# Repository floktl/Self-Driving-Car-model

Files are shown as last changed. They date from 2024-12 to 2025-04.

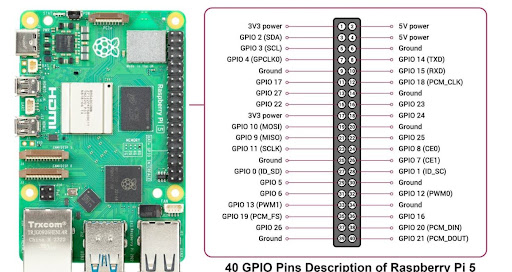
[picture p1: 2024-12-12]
Documentation/pinout_raspberry.jpg

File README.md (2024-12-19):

# Self-Driving Car Model 🚗🤖

Welcome to the **Self-Driving Car Model** project! This repository hosts the development of a small-scale self-driving car designed to provide hands-on experience in embedded systems and robotics applications. Whether you're a hobbyist, student, or professional looking to delve into autonomous vehicle technology, this project offers a comprehensive platform to learn, experiment, and innovate.

## Table of Contents
- [About the Project](#about-the-project)
- [Goals](#goals)
- [Learning Benefits](#learning-benefits)
- [Features](#features)
- [Technologies Used](#technologies-used)
- [Getting Started](#getting-started)
  - [Prerequisites](#prerequisites)
- [Usage](#usage)
- [Contributing](#contributing)
- [License](#license)
- [Contact](#contact)

## About the Project

The **Self-Driving Car Model** is an educational and experimental project aimed at developing a miniature autonomous vehicle. By integrating various components such as sensors, microcontrollers, and motor drivers, the project simulates the functionalities of full-scale self-driving cars. This model serves as a practical tool for understanding the complexities of embedded systems, robotics, and artificial intelligence in the context of autonomous navigation.

## Goals

- **Hands-On Learning:** Provide a tangible platform to apply theoretical knowledge in embedded systems and robotics.
- **Skill Development:** Enhance skills in programming, circuit design, sensor integration, and system debugging.
- **Autonomous Navigation:** Implement algorithms for obstacle detection, path planning, and decision-making.
- **Community Collaboration:** Foster a collaborative environment where contributors can share ideas, improvements, and innovations.
- **Scalability:** Design the model to be easily scalable for more complex projects in the future.

## Learning Benefits

Engaging with the Self-Driving Car Model project offers numerous educational advantages:

- **Embedded Systems:** Gain experience with microcontrollers, real-time operating systems, and hardware interfacing.
- **Robotics:** Understand the mechanics of vehicle movement, sensor integration, and actuator control.
- **Programming:** Develop proficiency in languages such as Python, C/C++, and utilize frameworks for robotics and AI.
- **Sensor Fusion:** Learn to integrate and interpret data from various sensors like Ultrasonic, and cameras.
- **Algorithm Development:** Implement and optimize algorithms for navigation, obstacle avoidance, and decision-making.
- **Troubleshooting:** Enhance problem-solving skills through debugging hardware and software issues.
- **Project Management:** Experience the lifecycle of a robotics project from conception to deployment.

## Features

- **Autonomous Navigation:** Navigate predefined tracks with dynamic obstacle avoidance.
- **Sensor Integration:** Utilize multiple sensors for environment perception, including ultrasonic sensors, cameras, and IMUs.
- **Real-Time Processing:** Implement real-time data processing for immediate decision-making.
- **Remote Control:** Option to control the car manually via remote for testing and debugging.
- **Modular Design:** Easily interchangeable components and subsystems for flexible experimentation.
- **Data Logging:** Record sensor data and vehicle performance metrics for analysis.

## Technologies Used

- **Microcontroller:** Arduino Uno / Raspberry Pi
- **Programming Languages:** Python, C/C++
- **Sensors:** Ultrasonic sensors, Cameras
- **Motor Drivers:** L298N, TB6612FNG
- **Communication:** Wi-Fi modules
- **Software Frameworks:** ...
- **Power Supply:** Li-Po batteries, voltage regulators

### Prerequisites

- **Hardware:**
  - Small-scale car chassis
  - Microcontroller (Arduino/Raspberry Pi)
  - Motor drivers
  - Sensors (ultrasonic, cameras, ...)
  - Power supply components
  - Wiring and connectors

- **Software:**
  - Arduino IDE or Raspberry Pi OS
  - Python 3.x
  - ROS (optional for advanced features)
  - OpenCV library
  - Git

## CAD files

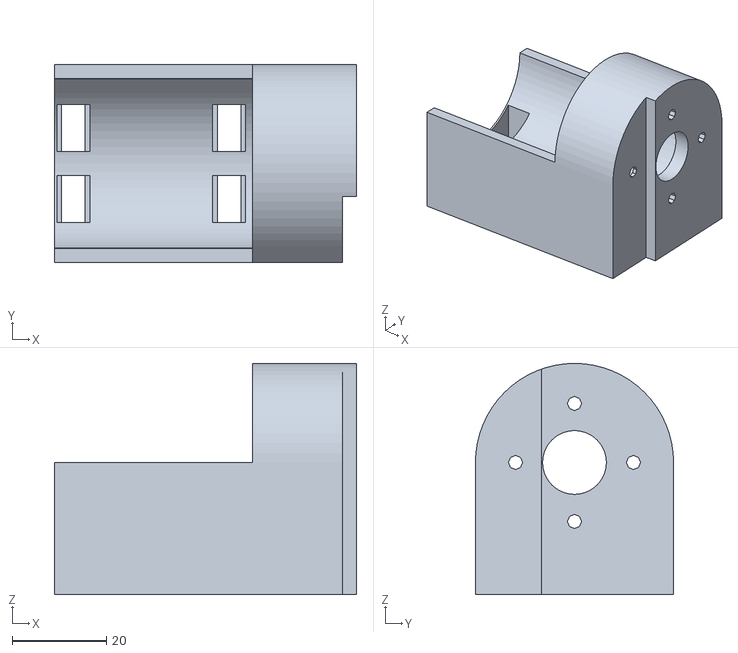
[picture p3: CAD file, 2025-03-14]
3d_printing/Main_motormount/motormount_v2_with_trail.stl
64.0 x 42.0 x 49.0

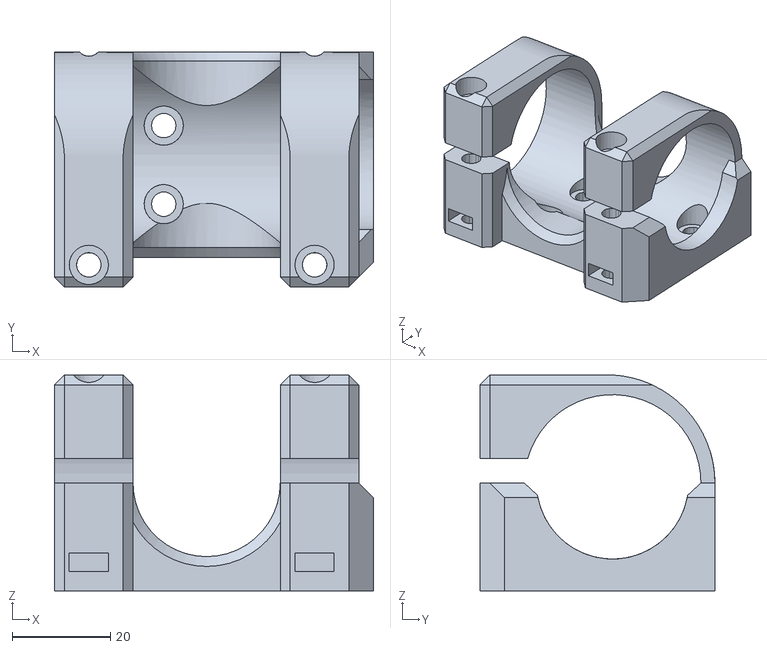
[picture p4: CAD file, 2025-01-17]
3d_printing/Main_motormount/motormount_v2_with_holes.stl
65.0 x 47.9 x 44.0

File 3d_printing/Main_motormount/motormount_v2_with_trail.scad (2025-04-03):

fn=64;		// Resolution for circular shapes
$fn=fn;		// Set global resolution for circles
//? fragment; sizes 
// Motor dimensions
motor_d=36;			// Motor diameter
motor_l=60;			// Motor length

// Plate parameters
plate_screw_d = 3;			// Diameter of plate screw holes
plate_screw_off = 25/2;		// Offset of screw holes from center
plate_gear_hole_d = 13.5;	// Diameter of gear hole
plate_gear_hole_l = 16;		// Depth of gear hole

// Bottom screw offsets
bottom_screw_1_gap_y = 18;
bottom_screw_2_gap_y = 15;
bottom_screw_1_gap_x = 4;
bottom_screw_2_gap_x = 37.5;

// Thickness parameters
plate_h=4;			// Plate thickness
bottom_t = 7;		// Bottom thickness
front_t = 3;		// Front thickness for casing walls

// Motor case calculations
motor_case_d = motor_d + front_t * 2;  // Outer diameter including front thickness

// Position offsets
motor_plate_y = 14;
motor_plate_x_off = 1;

// Subtracting inner components from the main shape
difference()
{
	translate([0,0,bottom_t])
	//? union?
	union()
	{
		// Add motor mounting plate
		//? translate
		translate([motor_l,motor_case_d/2,motor_case_d/2])
		rotate([0,90,0])
		plate(plate_h=plate_h);
		// Create the motor casing with subtractions for motor and cutouts
		difference()
		{
			//test();
			motor_case();

			// Subtract space for motor inside the case
			translate([0,front_t,front_t])
			motor();

			// Create cutout section inside motor case
			translate([0,0,motor_case_d/2])
			cube([motor_l-18, motor_case_d, motor_case_d/2]);
            
		}

		// Bottom support base for the motor casing (bottom plate)
		translate([0,0,-bottom_t])
		cube([motor_l+plate_h, motor_case_d, bottom_t]);
    difference() {   
    // Back support plate (ass)
     translate([-4,0,-bottom_t])
     cube([4,motor_case_d,(motor_case_d/2)+bottom_t]);
		 
     translate([-5,front_t,front_t])
		 motor();
    }
        
	}

	// Cutting out space for motor plate attachment
	translate([motor_l+motor_plate_x_off,0,0])
	cube([plate_h,motor_plate_y,motor_case_d+bottom_t]);

	// Add bottom screw holes (hidden in preview using #)
	#translate([0,front_t,4])
	bottom_screws();
}

// Creates the outer motor case
module motor_case()
{
	translate([0,motor_case_d/2,motor_case_d/2])
	rotate([0,90,0])
	cylinder(d=motor_case_d, h=motor_l);

	// Subtract a slot for motor fitting
	difference()
	{
		cube([motor_l+plate_h, motor_case_d, motor_case_d/2]);
		translate([0,motor_case_d/2,motor_case_d/2])
		rotate([0,90,0])
		cylinder(d=motor_case_d, h=motor_l+plate_h);
	}
}


// Places screws at the bottom of the casing
module bottom_screws()
{
	// back screws
	translate([bottom_screw_1_gap_x, (motor_d-bottom_screw_1_gap_y)/2, 0])
	{
		screwCube(); //right
		translate([0,bottom_screw_1_gap_y,0])
		screwCube(); //left
	}

	// front screw
	translate([bottom_screw_2_gap_x, (motor_d-bottom_screw_2_gap_y)/2, 0])
	{
		screwCube(); //right
		translate([0,bottom_screw_2_gap_y,0])
		screwCube(); //left
	}
}

module screwCube(w1=4,w2=6.7, depth=10, height=20)
{
    cube([w1,depth,height], true); // Bottom
    translate([0,0,8]) //5 (0 point) 3mm nut height
		cube([w2,depth,height], true); // Top
}

// Creates a screw with a head and shaft
module screw(d1=8, d2=5, l2=20, l1=50)
{
	cylinder(d=d1, h=l1, $fn=fn/4);  // Top screw (body)
	translate([0,0,-l2])
	cylinder(d=d2, h=l2, $fn=fn/4);  // Bottom screw (head)
}

// Creates the motor shape inside the casing
module motor()
{
	translate([0,motor_d/2,motor_d/2])
	rotate([0,90,0])
	union()
	{
		cylinder(d=motor_d, h=motor_l);  // Main motor body
		cylinder(d=plate_gear_hole_d, h=motor_l+plate_gear_hole_l);  // Gear shaft
	}
}

// Creates the motor mounting plate with screw holes
module plate(plate_h=1.5)
{
	rotate([0,0,180])
	difference()
	{
		linear_extrude(height = plate_h)
		difference()
		{
			circle(d=motor_case_d);       // Outer plate diameter
		  circle(d=plate_gear_hole_d);   // Gear hole cutout

			// Screw holes at each quadrant of the plate
			translate([plate_screw_off,0,0])
			circle(d=plate_screw_d,$fn=fn/8);

			translate([-plate_screw_off,0,0])
			circle(d=plate_screw_d,$fn=fn/8);

			translate([0,plate_screw_off,0])
			circle(d=plate_screw_d,$fn=fn/8);

			translate([0,-plate_screw_off,0])
			circle(d=plate_screw_d,$fn=fn/8);
		}
	}
}

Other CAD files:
3d_printing/Main_motormount/mounting.scad
3d_printing/Main_motormount/motormount_mod.scad

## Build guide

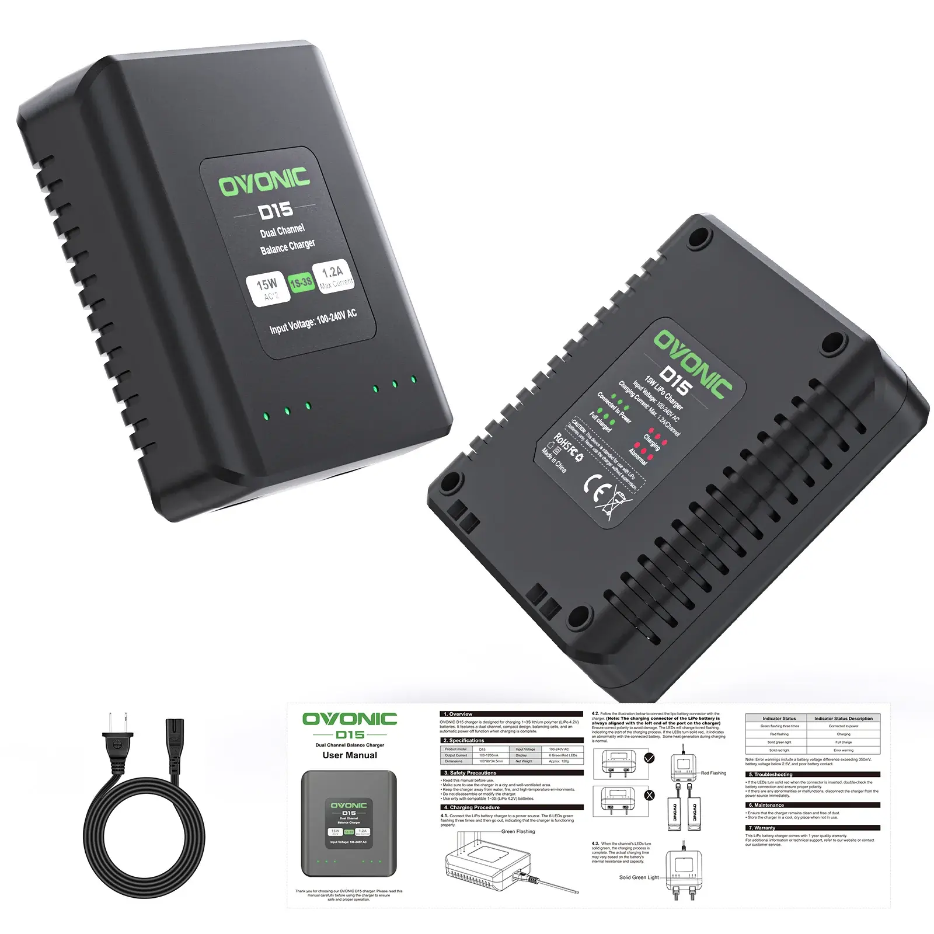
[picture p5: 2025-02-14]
Documentation/Datasheets/Main_battery_manual.jpeg

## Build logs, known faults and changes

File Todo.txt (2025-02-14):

Currently possible:
1. resolve raspberry connection issue
-connect to raspberry
-establish wireless communucation without 42 Wifi (maybe through server)
2.  Draw electrical schematic
-Done, but needs check again, bus connection between rasp and arduino necessary
3.  Get radio signal transmitter/receiver to avoid connection via SSH
-find and buy receiver and transmitter
4. Implement ISP/I2C connection between Raspberry Pi and Arduino to transfer bidirectional data and signals
-needs raspberry access

Soon possible:
1. Fix motor mount CAD and print new model
2. Test code, especially the main motor
-Testing main motor, for that CAD for motormount needs tbd

Parallel:
1. Design first simple PCB with Arduino and Raspberry Pi still connected
-part time work, not restricted through other points

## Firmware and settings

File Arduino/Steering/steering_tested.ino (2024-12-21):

#include <Servo.h>

// Pin declarations for the Servo and Distance Sensor
Servo myservo;
int pos = 90;  // Position of the servo set to Center.
int pin12 = 12;
int pin11 = 11;
int leftPin = 3;  // Arduino pin for left signal
int rightPin = 2; // Arduino pin for right signal

// Pins for Distance Sensor (HC-SR04)
const int trigPin = 6;  // TRIG pin connected to Arduino Pin 6
const int echoPin = 7;  // ECHO pin connected to Arduino Pin 7

const unsigned int min_left = 50;
const unsigned int max_right = 130;gi
const unsigned int steer_speed = 10;
const unsigned int servo_delay_time = 10;

// Variables for Distance Sensor
long duration;
int distance;

void setup() {
  pinMode(pin12, OUTPUT);
  pinMode(pin11, OUTPUT);
  pinMode(leftPin, INPUT);  // Set leftPin as input
  pinMode(rightPin, INPUT); // Set rightPin as input
  myservo.attach(9);  // Attach the servo to pin 9
  Serial.begin(9600);  // Start serial communication at 9600 baud rate
  Serial.println("Arduino is ready.");

  // Set up Distance Sensor
  pinMode(trigPin, OUTPUT);
  pinMode(echoPin, INPUT);
}

void loop() {

  if (pos > max_right || pos < min_left)
    return;
  // Read the state of the left and right signals from Raspberry Pi
  int leftState = digitalRead(leftPin);   // Read the state of leftPin
  int rightState = digitalRead(rightPin); // Read the state of rightPin
  
  digitalWrite(pin12,HIGH);
  digitalWrite(pin11,LOW);

  // Read Distance Sensor
  // Send a LOW pulse to TRIG to ensure it starts in a clean state
  digitalWrite(trigPin, LOW);
  delayMicroseconds(2);

  // Send a HIGH pulse for 10 microseconds to trigger the sensor
  digitalWrite(trigPin, HIGH);
  delayMicroseconds(10);
  digitalWrite(trigPin, LOW);

  // Read the time it takes for the echo to return
  duration = pulseIn(echoPin, HIGH);

  // Calculate the distance in centimeters (speed of sound is ~343 meters/second or 0.0344 cm/microsecond)
  distance = duration * 0.0344 / 2;

  // Print the distance to the Serial Monitor
  Serial.print("Distance: ");
  Serial.print(distance);
  Serial.println(" cm");

  // If the distance is less than 10 cm, automatically turn left
  if (leftState != HIGH && rightState != HIGH && distance < 10 && distance > 0)
  {
    if (pos >= min_left)
    {
      if (pos + steer_speed > min_left)
        pos += steer_speed;
      myservo.write(pos);
      Serial.println("Object too close! Turning left automatically.");
      delay(servo_delay_time);  // Add a small delay between readings to stabilize the sensor

    }
  }

  // Otherwise, move the servo based on left or right signal
  else
  {
    if (leftState == HIGH)
    {  // If the left signal is HIGH, move the servo left
      Serial.println("Left");
      if (pos - steer_speed > min_left)
      {
        pos -= steer_speed;  // Prevent the position from going below 0
        myservo.write(pos);
        delay(servo_delay_time);  // Small delay for smooth movement
      }
    }

    if (rightState == HIGH)
    { // If the right signal is HIGH, move the servo right
      Serial.println("Right");
      if (pos + steer_speed < max_right)
      {
        pos += steer_speed; // Prevent the position from going above 180
        myservo.write(pos);
        delay(servo_delay_time);  // Small delay for smooth movement
      }
    }
  }
}

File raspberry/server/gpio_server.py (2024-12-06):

# **************************************************************************** #
#                                                                              #
#                                                         :::      ::::::::    #
#    gpio_server.py                                     :+:      :+:    :+:    #
#                                                     +:+ +:+         +:+      #
#    By: flo <flo@student.42.fr>                    +#+  +:+       +#+         #
#                                                 +#+#+#+#+#+   +#+            #
#    Created: 2024/11/25 16:45:27 by fkeitel           #+#    #+#              #
#    Updated: 2024/11/29 16:27:43 by flo              ###   ########.fr        #
#                                                                              #
# **************************************************************************** #

#-------------------------------------------------------------------------------
# 	script to send the pin status of the raspberry pi GPIO pins using sockets
#	with json tcp protocolls for data transmissing
#	usuage (on raspberry pi): python3 gpio_server.py &
#	then start client on the client pc
#-------------------------------------------------------------------------------

import RPi.GPIO as GPIO
import socket
import json
import time
from threading import Lock

# GPIO setup
GPIO.setmode(GPIO.BCM)
ALL_GPIO_PINS = [2, 3, 4, 5, 6, 7, 8, 9, 10, 11, 12, 13, 14, 15, 16,
                17, 18, 19, 20, 21, 22, 23, 24, 25, 26, 27]

# Dictionary to store pin modes (default to "unknown")
monitored_pins = {pin: "unknown" for pin in ALL_GPIO_PINS}
lock = Lock()

# Check pin modes (input/output/unknown) without altering configuration
def detect_pin_modes():
    with lock:
        for pin in ALL_GPIO_PINS:
            try:
                # Try reading the pin state without changing it
                GPIO.setup(pin, GPIO.IN) 	# Temporarily set as input
                GPIO.setup(pin, GPIO.OUT) 	# Temporarily set as output
                GPIO.setup(pin, GPIO.IN, pull_up_down=GPIO.PUD_OFF)  # Reset
                monitored_pins[pin] = "input"
            except RuntimeError:
                # If the pin is already configured as output, mark it as "output".
                monitored_pins[pin] = "output"
            except Exception:
                # If an error occurs, mark the pin's mode as "unknown".
                monitored_pins[pin] = "unknown"

# Set up the server socket for communication.
HOST = "0.0.0.0"  # Listen on all available network interfaces.
PORT = 65432  # Port number for the server to listen on.
# AF_INET: Specifies the socket will use IPv4 protocol for communication.
# SOCK_STREAM: Indicates that socket will use TCP (Transmission Control Protocol)
server = socket.socket(socket.AF_INET, socket.SOCK_STREAM)  # Create a TCP socket.
server.bind((HOST, PORT))  # Bind the socket to the specified host and port.
server.listen(1)  # Start listen for inc. conn., allowing one client at a time.

print("Server listening for connections...")
#Server is now set up and waiting for connections

try:
    while True:  # Main loop to accept and handle client connections.
        conn, addr = server.accept()  # Wait for a client to connect.
        print(f"Connection from {addr}")  # Log the client's address.

        try:
            while True:  # Handle communication with the connected client.
                detect_pin_modes()  # Detect the current mode of each pin.

                # Collect the state and mode of all pins dynamically.
                with lock:  # Ensure thread-safe access to `monitored_pins`.
                    pin_states = {
                        # f-string syntax, {pin} dynamically inserts value of pin.
                        f"GPIO {pin}": {
                            "mode": monitored_pins[pin],  # Retrieve mode of pin.
                            # get pin state
                            "state": GPIO.input(pin) if monitored_pins[pin]
                            	in ("input", "output") else "N/A"
                        }
                        for pin in ALL_GPIO_PINS  # Process all pins.
                    }
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

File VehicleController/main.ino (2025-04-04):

/* ************************************************************************** */
/*                                                                            */
/*                                                        :::      ::::::::   */
/*   main.ino                                           :+:      :+:    :+:   */
/*                                                    +:+ +:+         +:+     */
/*   By: gstronge <gstronge@student.42heilbronn.    +#+  +:+       +#+        */
/*                                                +#+#+#+#+#+   +#+           */
/*   Created: 2024/12/20 22:53:24 by Florian Kei       #+#    #+#             */
/*   Updated: 2025/04/04 14:30:58 by gstronge         ###   ########.fr       */
/*                                                                            */
/* ************************************************************************** */

/*
	C++ Program to steer the vehicle automously or via remote control
 */

#include "VehicleController.h"

// Pin Configuration on arduino
ESCMotor mainMotor(13);
SteeringServo steering(10);	// Pin, max left angle, max right angle

// trigger and echo pins for sensor
DistSensor frontSensor(4, 6);//(trigger, echo)
DistSensor leftSensor(5, 7);
DistSensor rightSensor(11, 12);

// constructing the vehicle class with subcomponents
VehicleController car(mainMotor, steering, frontSensor, leftSensor, rightSensor);


void setup() {
	car.vehicle_setup();
}

// main loop
void loop() {
	car.loop();
}

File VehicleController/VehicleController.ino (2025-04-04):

/* ************************************************************************** */
/*                                                                            */
/*                                                        :::      ::::::::   */
/*   VehicleController.ino                              :+:      :+:    :+:   */
/*                                                    +:+ +:+         +:+     */
/*   By: gstronge <gstronge@student.42heilbronn.    +#+  +:+       +#+        */
/*                                                +#+#+#+#+#+   +#+           */
/*   Created: 2024/12/20 22:33:13 by Florian Kei       #+#    #+#             */
/*   Updated: 2025/04/04 14:15:01 by gstronge         ###   ########.fr       */
/*                                                                            */
/* ************************************************************************** */

#include "VehicleController.h"

// ----------------------- VehicleController implementation -------------------
VehicleController::VehicleController(ESCMotor motor,
									SteeringServo servo,
									DistSensor front,
									DistSensor left,
									DistSensor right)
	: mainMotor(motor),
		steering(servo),
		frontSensor(front),
		leftSensor(left),
		rightSensor(right),
		minFrontDist(10) {}

// setup function to setup all pins and start values for the vehicle
void VehicleController::vehicle_setup()
{
	// init all subcomponents
	mainMotor.initialize();
	steering.initialize();
	frontSensor.initialize();
	leftSensor.initialize();
	rightSensor.initialize();

	// set pins from raspberry as input
	pinMode(leftPin, INPUT);  // Set leftPin as input
	pinMode(rightPin, INPUT); // Set rightPin as input
	pinMode(upPin, INPUT); // Set rightPin as input
	pinMode(downPin, INPUT); // Set rightPin as input

	// debugging
	Serial.begin(9600);
	Serial.println("Vehicle Initialized and Ready!");
  steering.center();
  }

int counter = 0;
int distanceFront = 100;

// main loop. which will run continiously
void VehicleController::loop()
{
	Serial.println("xxxxx");
	counter++;
	if (counter % 20 == 0)
		distanceFront = frontSensor.getDistance();
	// int distanceLeft = leftSensor.getDistance();
	// int distanceright = rightSensor.getDistance();

	leftState = digitalRead(leftPin);   // Read the state of raspberry left
	rightState = digitalRead(rightPin); // Read the state of raspberry right
	upState = digitalRead(upPin); // Read the state of raspberry right
	downState = digitalRead(downPin); // Read the state of raspberry right
	// Serial.println("Position: ");
	// Serial.println(steering.getPosition());

		// steer with sensor overrides user steering
	Serial.println(distanceFront);
	if (SENSOR_OVERRIDES && distanceFront < minFrontDist && downState == LOW)//) || distanceLeft < minSideDist  || distanceRight < minSideDist))
		sensorSteering(distanceFront);//), distanceLeft, distanceright);	// steer with sensor
	else // manual control over remote commands
		{
		if (leftState == HIGH && rightState == LOW)
		{  // If the left signal is HIGH, move the servo left
			steering.steerLeft(steerSpeed);
			Serial.println("===================RRRRRRRRRRRRR");
		}
		else if (rightState == HIGH && leftState == LOW)
		{ // If the right signal is HIGH, move the servo right
			Serial.println("-------------------------------------LLLLLLLL");
			steering.steerRight(steerSpeed);
		}
		if (upState == HIGH)
		{
			if (mainMotor.getSpeed() < 1600)
			mainMotor.setSpeed(1600);
		mainMotor.setSpeed(mainMotor.getSpeed() + driveSpeed);
	}
	else if (downState == HIGH)
	{
			Serial.println("HIGHHIGHHIGH");
			if (mainMotor.getSpeed() > 1400)
				mainMotor.setSpeed(1400);
			mainMotor.setSpeed(mainMotor.getSpeed() - driveSpeed);
		}
		else if (mainMotor.getSpeed() > 1500)
		{
			mainMotor.setSpeed(mainMotor.getSpeed() - driveSpeed);
		}
		else if (mainMotor.getSpeed() < 1500)
		{
			mainMotor.setSpeed(mainMotor.getSpeed() + driveSpeed);
		}

	}
	delay(servoDelayTime);
}

//------------------------------- private functions ----------------------------


void VehicleController::sensorSteering(int distanceFront)
{
	Serial.println("sensor steering");
	if (distanceFront < minFrontDist)
	{
		while (constrain(mainMotor.getSpeed(), 1400, 1600))
		{
			mainMotor.setSpeed(mainMotor.getSpeed() - 50);
			delay(servoDelayTime);
		}
	}
	
	// if (distanceFront != minFrontDist)
	// {
	// 	adjustSpeed(distanceFront);
	// 	steerVehicle(distanceLeft, distanceright);
	// 	minFrontDist = distanceFront;
	// }
}

// adjust the speed, if the front distance is free of objects
void VehicleController::adjustSpeed(int distanceFront)
{
	int speed = mainMotor.getSpeed();

	speed = (speed > 1500) ? speed - 100 : speed + 100;
	mainMotor.setSpeed(speed);
}

//	steer the vehcicle,
void VehicleController::steerVehicle(int distanceLeft, int distanceright)
{
	if (distanceLeft < side_max_distance && distanceLeft > 0)
	{
		if (steering.getPosition() >= steering.minLeft)
		{
			steering.steerLeft(steerSpeed);
		}
	}
	else if (distanceright < side_max_distance && distanceright > 0)
	{
		if (steering.getPosition() <= steering.maxRight)
		{
			steering.steerRight(steerSpeed);
		}
	}
	else if (steering.getPosition() != steering.middle_pos)
	{
		steering.center();
	}
}

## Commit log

2024-11-25 added server.py file for pin status reading of pi
2024-11-25 added client file and pin change test file
2024-11-25 shifted pin_change int o raspberry folder
2024-12-06 added arduino code
2024-12-06 Steering control from Keyboard using Arduino + Raspberry
    We were are able to control the Servo Motor movement from Keyboard using Arduino + Raspberry.
2024-12-09 added steering cleanup, a more robust function for steeringm, added steering_tested, steering works now with distance sensor as well
2024-12-16 Motor speed control based on distance sensor
2024-12-16 added improved speed control, but still buggy, need for further fixes
    [Steering_speed_control.ino, steering_tested.ino]
2024-12-21 implemented functioning side detection and automate steering for left and right
2024-12-21 added raspberry control for steering
2025-01-03 adjusted steering_py
2025-01-17 motor mounting modifications
    [motormount_mod.scad, motormount_v2_with_holes.stl, mounting.scad]
2025-01-20 changed python steering script, however blinkn issue and simultanisly steering and speed not possible yet
    [steer_direction.py]
2025-01-26 updated remoter control script with multithreading, changed repo structure
    [motormount_mod.scad, motormount_v2_with_holes.stl, mounting.scad]
2025-02-01 Two remote_steering_test python version added to git. These two files try to solve that problem, how possible to use left/right and forward/backward in same time, with that way, the PIN will set back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
    [remote_steering_test1.py]
2025-02-01 modified remote steering script with pygame, works, only small bug
    [mock_gpio_library.py, remote_steering_test1.py, remote_steering_tested_works.py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]
2025-02-02 remote steering works, data visualzioation with pygame
2025-02-07 fixed error in main.ino where there were 2 x high_signal int variables declared
    [main.ino]
2025-02-09 added test kicad scheamtic
    [car_github_schematic.kicad_sch]
2025-02-14 github schematic
    [car_github_schematic.kicad_sch]
2025-02-14 added datasheets and implemented a schematic for the vehicle in current state
    [car_github_schematic.kicad_sch]
2025-02-14 added main battery charger datasheet
2025-02-24 added code to made driving motor work, fixed steering
    [ESC.ino, VehicleController.h, VehicleController.ino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]
2025-03-04 minor changes to turning speed, and what the driving motor does when initialising
2025-03-10 fixed so the car can drive forwards and backwards and steer left and right
    [ESC.ino, VehicleController.h, VehicleController.ino]
2025-03-14 updated model with square trail for screws
    [motormount_v2_with_trail.stl, mounting.scad]
2025-03-28 scad file for model with trails
    [motormount_v2_with_trail.scad]
2025-04-03 3d: added cutout for back support
    [motormount_v2_with_trail.scad]
2025-04-04 added functions to override the user steering if the front sensor is too close to an object
    [ESC.ino, VehicleController.h, VehicleController.ino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]
